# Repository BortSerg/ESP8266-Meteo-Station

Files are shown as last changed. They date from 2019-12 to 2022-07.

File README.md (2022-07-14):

# ESP8266-Meteo-Station
v14_07_2022.
1. Add auto load default settings in first start meteo station after firmware download.
2. Set DS18B20 outdoor sensor; BME280 room sensor.
3. Fix bug in 7-segment display light.
 
v11_02_2020.
1. Added the ability to update firmware via the web interface of the weather station. 
   You must go to the address http: // {IP Address} / update and specify *.bin firmware file.
2. Now there are 2 firmware in the project. With and without an RTC module. 
   In firmware without an RTC module, time is counted using the ESP8266 itself.

v07_02_2020.
Fix some bugs:
1. Fix display on the indicator of negative temperatures.
2. Fix changes the background color of the main web page at low temperatures.
3. Adding a button to adjust the brightness of the indicators on the main web page.
4. Decrease in manipulations at the first firmware of the device. Now you need to uncomment part of the code, flash, comment out and flash it again.

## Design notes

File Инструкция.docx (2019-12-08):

# Первый запуск

При первом включении метеостанции индикация на дисплее включается не сразу, некоторое время необходимо подождать, так как идет сканирование сетей, затем станция запускается в режиме точки доступа. На индикаторе в виде бегущей строки пробежит IP адрес 192.168.4.1. Для подключения к ней и дальнейшей конфигурации необходимо в списке доступный беспроводных сетей выбрать и подключиться к точке ESP8266.

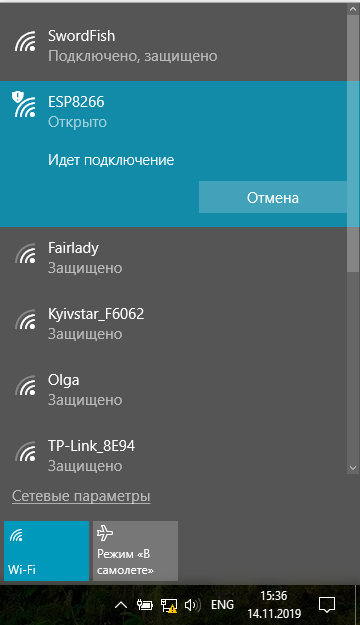
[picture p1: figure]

Далее в адресной строке браузера необходимо вписать данный IP адрес. Поле загрузки главной страницы с отображаемыми показаниями можно приступать к настройке метеостанции. В разделе Wi-Fi/AP задаются имя/пароль от вашей домашней беспроводной сети и имя/пароль точки доступа. Если у Вас соединения не защищенные паролем, то графы с паролями необходимо оставить пустыми. ВНИМАНИЕ! Во избежание некорректной работы метеостанции, графа с именем точки доступа должна быть ВСЕГДА заполнена. В случае неполадок в домашней беспроводной сети это позволит Вам подключиться к ней и изменить конфигурации. Графу с паролем можно не заполнять, если неуверены, что не забудете его в дальнейшем.

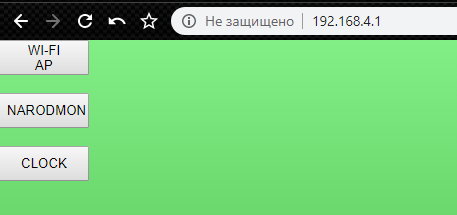
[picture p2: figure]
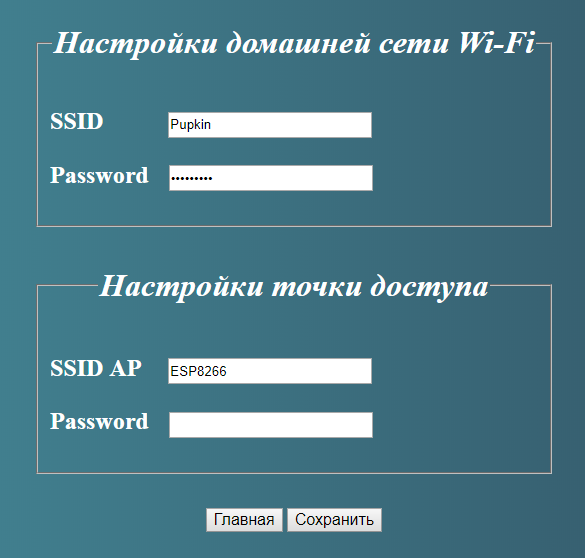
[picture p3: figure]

После конфигурирования сетевых параметров необходимо нажать кнопку «сохранить», а затем вручную перезагрузить устройство, отключив питание.

Без подключения к сети и доступа в интернет (работа в режиме точки доступа) невозможна отправка данных на Narodmon.ru и синхронизация часов с NTP серверами точного времени. Часы, в данном режиме работы, нужно будет корректировать вручную.

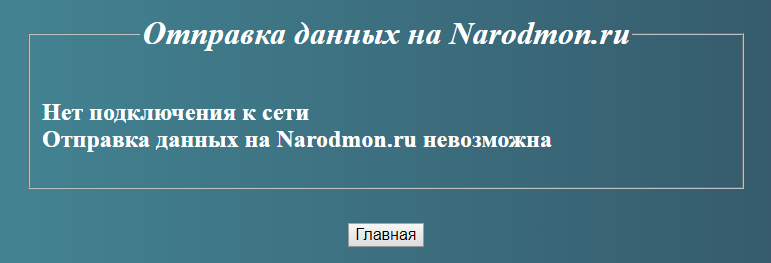
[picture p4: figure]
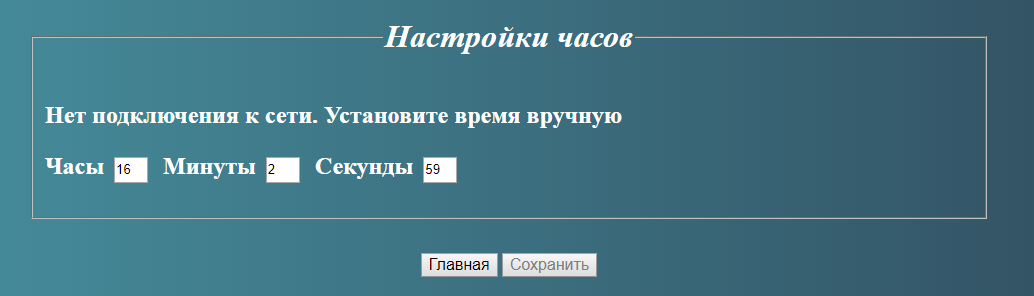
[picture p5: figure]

После перезагрузки, если Вы указали правильные параметры домашней сети, метеостанция подключится к вашему Wi-Fi роутеру и на индикаторе снова пробежит IP адрес, а точка доступа ESP8266 исчезнет. Подключившись к Вашему роутеру необходимо в адресной строке браузера ввести уже новый IP адрес.

Новый IP адрес можно будет использовать для доступа к метеостанции из вашей домашней сети. Теперь Вам будут доступны разделы с конфигурациями часов и Narodmon.ru.

# Narodmon.ru

Что такое Narodmon.ru? Это основанный в 2011 году краудфандинговый геоинформационный проект по отображению на карте мира и контролю (на ПК, смартфонах и других гаджетах) показаний датчиков своих участников (температуры, влажности, атм.давления, скорости и направления ветра, радиации, энергопотребления и любых других величин), а также частных и городских веб-камер для публичного или приватного просмотра.

Как это сделать? Сперва необходимо зарегистрироваться на сайте. Далее на метеостанции в соответствующих настройках разрешить ей отправку данных на сайт и указать таймаут отправки данных (меньше 5 минут нельзя, такова политика сайта). Затем на сайте в вкладке «профиль» выбрать пункт «Мои датчики».

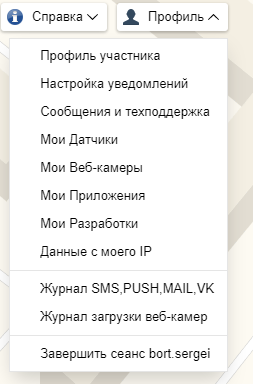
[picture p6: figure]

Далее кнопка «Добавить» и указать MAC метеостанции (для примера возьмем MAC CC:50:E3:2E:8A:79). Добавление возможно только после успешной передачи показаний метеостанции на сервер и верно указанного MAC.

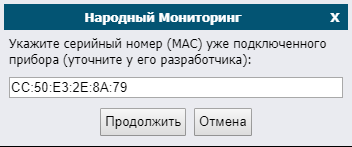
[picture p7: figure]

Если все указано верно и данные доставлены на сервера проекта, то в таблице ниже появятся данные которые приходят с метеостанции:

BME280P – атмосферное давление (мм.рт.ст.),

BME280Т – температура на улице (град. Цельсия),

BME280Н – влажность воздуха (%),

8e6f579970903c8 – датчик комнатной температуры (град. Цельсия).

Датчик комнатной температуры нельзя выводить в общий доступ.

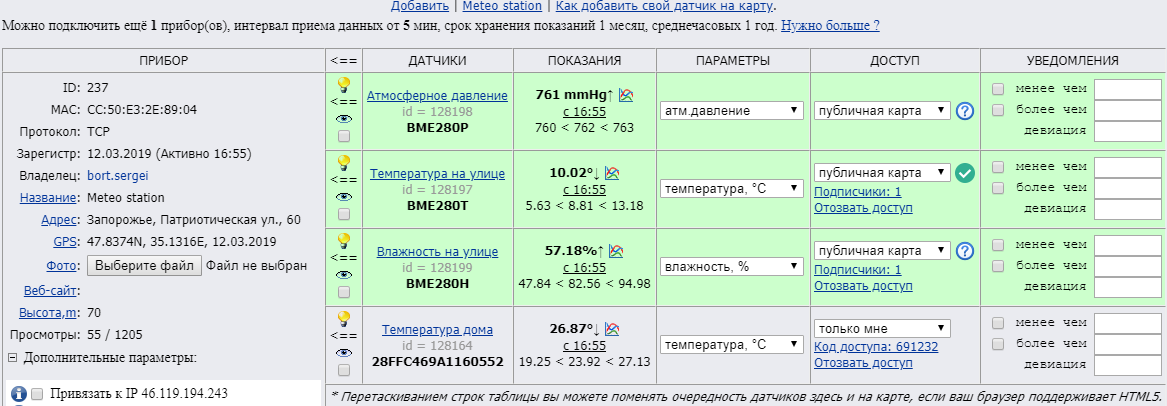
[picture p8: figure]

Выводя показания своих датчиков в публичный доступ, Вы обязуется разместить их "на улице" и принять меры по снижению влияния среды (прямых солнечных лучей, осадков, нагрева от стен строения) на достоверность показаний.

У проекта Narodmon есть мобильное приложение, которое позволит Вам с любой точки мира просматривать данные от ваших датчиков.

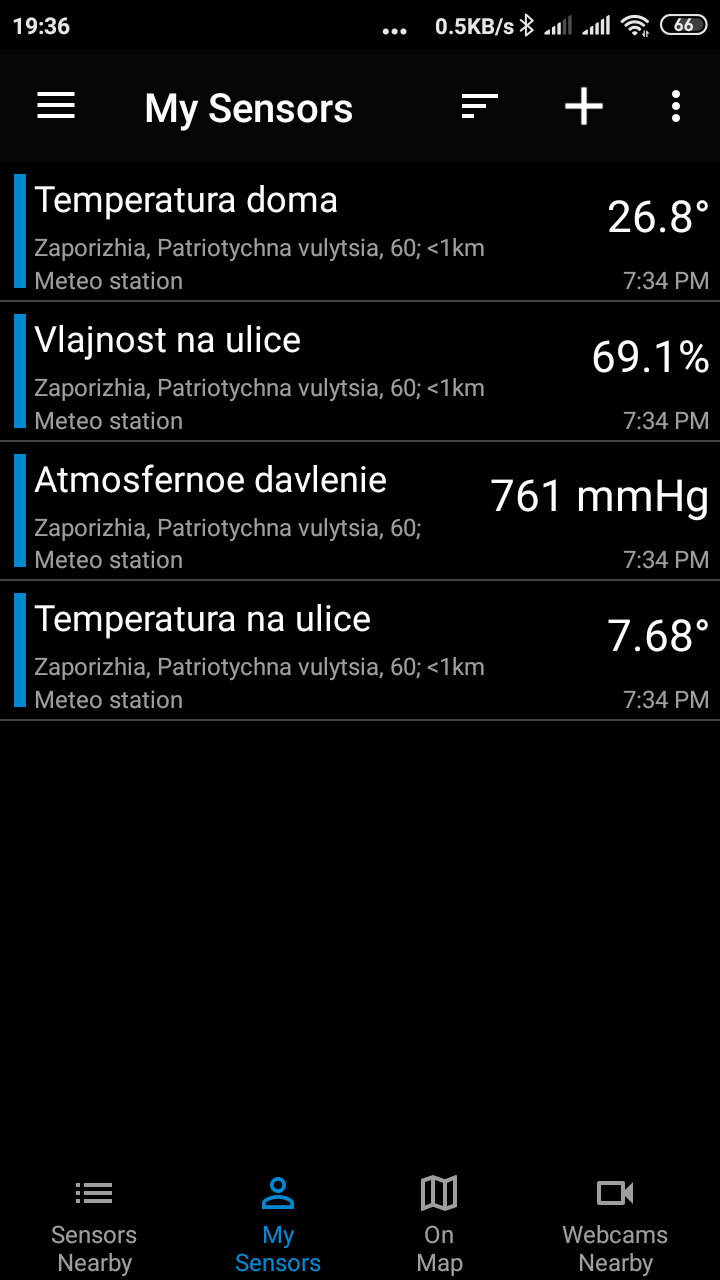
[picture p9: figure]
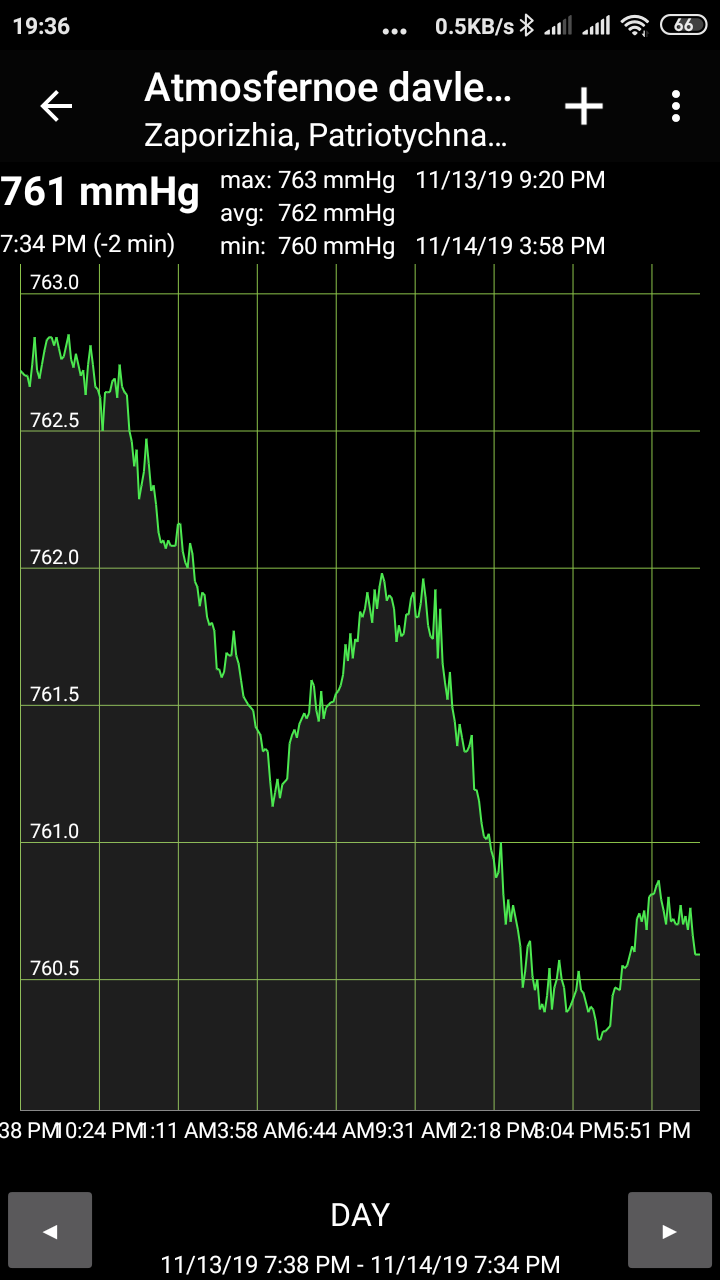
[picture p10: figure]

# Часы

Часы имеют функцию корректировки времени по NTP серверам точного времени. Для этого в конфигурации часов необходимо выбрать пункт «синхронизировать с NTP сервером», указать часовой пояс GMT (Greenwich Mean Time) в приделах от -11..0..12 и указать период с которым метеостанция будет сверять время с сервером. Интервал устанавливается в пределах от 1 часа до 168 часов (1 неделя).

Внутри метеостанции установлена микросхема часов реального времени (RTC DS1307Z) со своей памятью, что позволяет сохранять ход времени, даже если выключить метеостанцию. Точность хода составляет ±1-3 сек. в час. Если разница времени метеостанции и сервера NTP меньше 1 минуты, то синхронизация не производится.

Для перевода часов на летнее и зимнее время необходимо изменить часовой пояс GMT в большую или меньшую сторону на 1. Автоматический переход на летнее и зимнее время пока не предусмотрен в данной версии прошивки.

Если же в корректировке времени нет необходимости данную функцию можно отключить и выставить время вручную.

# Психотермометрическая будка

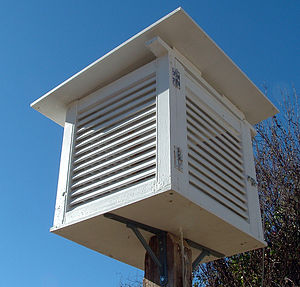
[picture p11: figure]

Датчик BME280 необходимо разместить на улице исключив попадание на него прямых солнечных лучей. В идеале такие датчики необходимо размещать в метеорологических будках, но поскольку на оконном отливе такое сооружение разместить проблематично, можно сделать импровизированную будку.

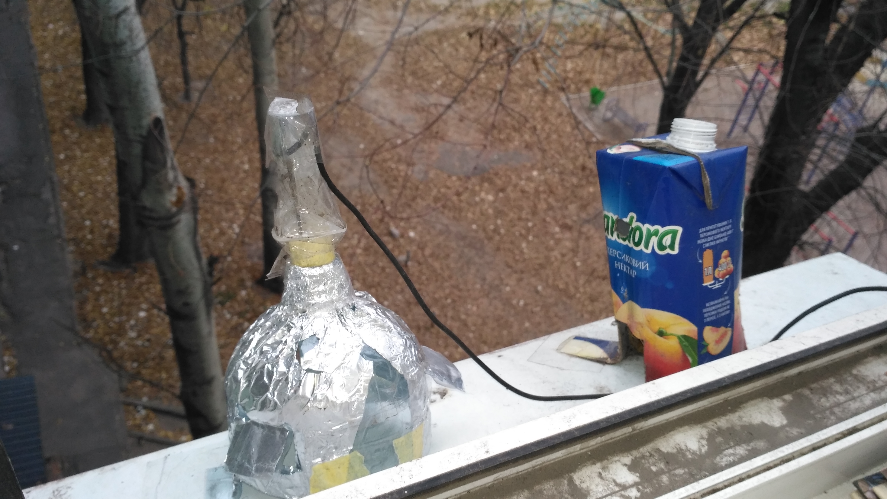
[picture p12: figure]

Корпус шприца идеально проходит в горлышко пластиковой бутылки от воды/напитка или в горлышко картонной упаковки сока. Если корпус из бутылки, то необходимо обернуть ее не проводящим свет материалом (фольга). Обязательно необходимо сделать отверстия для проветривания, это позволит не повышаться температуре внутри, при попадании прямых солнечных лучей, и не скапливаться конденсату, что может влиять на показания влажности.

Хоть наконечник штока шприца имеет резиновую прокладку, что обеспечивает хорошую гидроизоляцию, его можно обернуть скотчем, зафиксировав таким образом кабель и создав дополнительную гидроизоляцию. Кабель лучше всего направить вниз, так во время дождя по нему не будет стекать вода внутрь.

Пример импровизированной «будки»

# Дополнительные функции

1) Метеостанция имеет возможность изменять яркость свечения 7-сегментного индикатора. Для этого необходимо в адресной строке браузера ввести вручную [IP адрес]/settings_Light (http://192.168.1.4/settings_Light).

После этого будет доступно изменение яркости индикатора

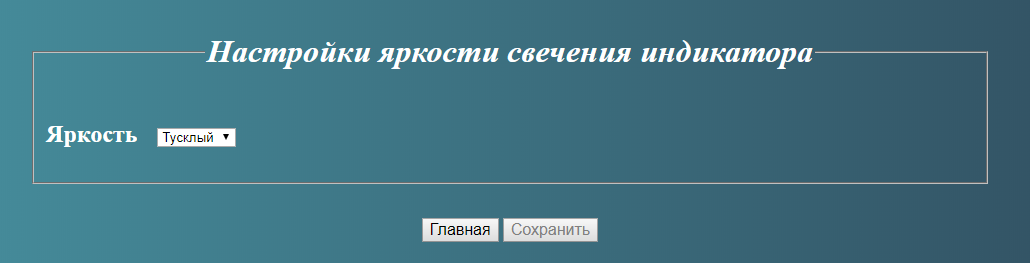
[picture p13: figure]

2) Имеется возможность перезагружать метеостанцию программно, но данная функция не всегда работает стабильно и иногда приводит к зависанию. Для перезагрузки необходимо в адресной строке браузера ввести [IP адрес]/reboot

После этого должна произойти перезагрузка и браузер автоматически перенаправит Вас на главную страницу.

Если же это привело к зависанию, то необходимо просто отключить питание метеостанции, а затем заново подключить.

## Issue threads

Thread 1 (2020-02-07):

ESP8266-Meteo-Station 07_02_2020

BortSerg, 2020-02-07:
1. Fix display on the indicator of negative temperatures
2. Fix for changing the background color of the main web page at low temperatures
3. Adding a button to adjust the brightness of the indicators on the main web page
4. Decrease in manipulations at the first firmware of the device. Now you need to uncomment part of the code, flash, comment out and flash it again.

Closed 2021-08-14.

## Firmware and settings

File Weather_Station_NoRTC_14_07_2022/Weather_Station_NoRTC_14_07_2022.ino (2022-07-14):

#include <ArduinoOTA.h>
#include <OneWire.h>
#include <ESP8266WiFi.h>
#include <WiFiClient.h>
#include <ESP8266WebServer.h>
#include <ESP8266HTTPUpdateServer.h>
#include <DallasTemperature.h>
#include "sntp.h"
#include <BME280I2C.h>
#include <Wire.h>
//#include <time.h>                            // закоментировать если не используется RTC
#include <TM1637.h>
#include <EEPROM.h>
//#include <WiFiClientSecure.h>              // для отправки в Telegram
#include <Ticker.h> //если не использовать модуль часов RTC раскоментировать

BME280I2C::Settings settings(
    BME280::OSR_X1,
    BME280::OSR_X1,
    BME280::OSR_X1,
    BME280::Mode_Forced,
    BME280::StandbyTime_1000ms,
    BME280::Filter_Off,
    BME280::SpiEnable_False,
    0x76 // I2C address. I2C specific.
);
BME280I2C bme(settings);

// I2C pins                                 //Wemos ESP8266
#define SDA_pin 4 // D2 pin
#define SCL_pin 5 // D1 pin

// инициализация oneWire и DS18B20
#define ONE_WIRE_BUS D4          // вывод к которому подключен DS18B20 он же GPIO1
#define TEMPERATURE_PRECISION 12 // точность бит. Если глючит или врет, уменьшить с 12 до 9

//  инициализация и установка адреся RTC
#define DS1307_I2C_ADDRESS 0x68

// определение пинов для вывода на индикаор ТМ1637
#define CLK D6
#define DIO D5

//Создаём объект класса TM1637, в качестве параметров передаём номера пинов подключения
TM1637 tm1637(CLK, DIO);
bool changeClock = false;
bool notChangeClock = false;

int NumberOfDevices; //сколько датчиков DS18B20 в системе.

// Переменные для часов
// uint32 Time;                              //время в UNIX формате
String timefull;        //время в формате dayweek month day 00:00:00 year
byte hours;             //часы
byte minutes;           //минуты
byte seconds;           //секунды
byte dayOfWeek;         //день недели
byte dayOfMonth;        //число месяца
byte month;             //месяц
byte year;              //год
byte sinc_count = 0;    //счечик попыток синхронизации часов
bool point_flag = true; //флаг для мигания разделителем при отображении часов
bool sync_clock = true; //флаг на разрешение синхронизации часов с сервером

// Переменные для таймингов
unsigned long previousMillis_TM1637 = 0;
unsigned long previousMillis_NM = 0;
unsigned long previousMillis_TL = 0;
unsigned long sync_previousMillis = 0;
unsigned long interval_TM1637 = 10000;  //интервал через который происходит смена значений на индикаторе
unsigned long interval_sync = 43200000; //интервал синхронизации часов
byte count = 0;                         //флаг смены значений на индикаторе
bool send_NM = true;                    //разрешение на отправку данных Narodmon.ru
unsigned long interval_NM = 300000;     //интервал отправки данных на Narodmon.ru
// bool          send_TL = true;               //разрешение на отправку данных Telegram
// unsigned long interval_TL = 300000;         //интервал отправки данных на Telegram

ESP8266HTTPUpdateServer httpUpdater;
ESP8266WebServer server(80);

WiFiClient client; // для отправки данных на narodmon.ru
// WiFiClientSecure httpsClient;               //для отправки даных в Telegram

OneWire oneWire(ONE_WIRE_BUS);
DallasTemperature DS18B20(&oneWire);

Ticker timer_clock; //объект класса, для вызова счетчика времени. Раскоментировать если нет RTC

// const uint16_t httpsPort = 443;             // порт Telegram bot
// const char* host = "api.telegram.org";      // хост Telegram bot
// SHA1 finger print of certificate use web browser to view and copy
// const char fingerprint[] PROGMEM = "bb dc 45 2a 07 e3 4a 71 33 40 32 da be 81 f7 72 6f 4a 2b 6b";
// String token = "";                          //api token
// String chat_id = "";                        //id чата с ботом
// String msg = "Start";                       //переменная для хранения сообщения которое будет отправленно в Telegram bot

struct ESP_Config
{                      //структура для хранения настроек метеостанции в EEPROM памяти. Переменные структуры записаны большими буквами, для их отличия от других глобальных переменных
  char MUSOR[16] = {}; //В начале сектора EEPROM содержатся какие-то данные ESP, запись туда важных данных нежелательна
  // Наименование в режиме клиента
  char WIFI_SSID[32] = {}; //имя сети
  char WIFI_PASSWORD[32] = {};
  // Параметры подключения в режиме точки доступа
  char AP_SSID[32] = {}; //имя точки доступа
  char AP_PASSWORD[32] = {};
  // Настройки часов
  int GMT = 0;               //часовой пояс
  bool SYNC_CLOCK = 0;       //разрешение на синхронизацию
  uint8_t INTERVAL_SYNC = 0; //интервал синхронизации часов
  // Настройки отправки данных на narodmon.ru
  bool SEND_NM = 0;        //разрешение на отправку данных Narodmon
  uint8_t INTERVAL_NM = 0; //интервал отправки данных
  // Настройки отправки сообщений в Telegram
  bool SEND_TL = 0;        //разрешение на отправку данных Telegram
  uint8_t INTERVAL_TL = 0; //интервал отправки данных
  char CHAT_ID[16] = {};   //Уникальный ID  чата
  char TOKEN[64] = {};     // API Token
  byte LIGHT = 0;          //Яркость 7-сегментного индикатора
  byte CONTROLL_VALUE = 0; //Контрольное значение = 88. Используется для определения загрузки дефолтных настроек при первом запуске
} Config;

void setup()
{

  Serial.begin(115200);
  Serial.println("");
  Serial.println("Soft ver. 14.07.2022");
  Serial.println("");
  EEPROM.begin(sizeof(Config)); //инициализация EEPROM памяти в размере = размеру структуры Config
  Serial.println("Инициализированно " + String(sizeof(Config)) + " byte EEPROM памяти");

  OTA_Update(); //подключение обновления по воздуху

  Read_Config(); // xтение конфига из EEPROM памяти конфигураций

  if (Config.CONTROLL_VALUE != 88) // проверка считаных с памяти данных. Если контрольное значение не верно, то записать дефолтные настройки
  {
    String ssid = "WiFiName";
    String pass = "";
    String ap_ssid = "ESP8266";
    String ap_pass = "";
    strcpy(Config.WIFI_SSID, ssid.c_str());
    strcpy(Config.WIFI_PASSWORD, pass.c_str());
    strcpy(Config.AP_SSID, ap_ssid.c_str());
    strcpy(Config.AP_PASSWORD, ap_pass.c_str());
    Config.SEND_NM = 5;
    Config.GMT = 0;
    Config.SYNC_CLOCK = 1;
    Config.INTERVAL_NM = 5;
    Config.INTERVAL_SYNC = 12;
    Config.LIGHT = 2;
    Config.CONTROLL_VALUE = 88;
    save_Config();
  }

  TM1637_init(); //Инициализация модуля TM1637

  SNTP_server_set(); //установка таймзоны и sntp серверов

  WiFi_init(); //подключение к сети и синхронизация часов/поднятие точки доступа

  Dalas18B20(); //поиск и инициализация датчиков DS18B20

  BME(); //поиск и инициализация датчика BME/BMP

  Init_html(); //инициализация HTML страниц сервера

  Serial.println("Temperature web server started!\n");

  timer_clock.attach(1, clock_); //прерывание для часов.  Раскоментировать если нет RTC

  IP_address_run(); //вывод IP адреса

  if (Config.SYNC_CLOCK == true & WiFi.status() == WL_CONNECTED)
    SyncRealTimeClock();
}

void loop()
{
  server.handleClient();
  ArduinoOTA.handle();
  delay(100);

  unsigned long currentMillis = millis();

  byte clock_view_count = 0;
  if ((currentMillis - previousMillis_TM1637 > interval_TM1637) & count == 0) //вывод часов
  {
    previousMillis_TM1637 = currentMillis;
    while (clock_view_count < 11)
    {
      viewTime();
      delay(1000);
      clock_view_count++;
    }
    clock_view_count = 0;
    count++;
  }

  if ((currentMillis - previousMillis_TM1637 > interval_TM1637) & count == 1) //вывод температуры в помещении
  {
    tm1637.point(false);
    previousMillis_TM1637 = currentMillis;
    getTM1637TemperatureRoom();
    count++;
  }

  if ((currentMillis - previousMillis_TM1637 > interval_TM1637) & count == 2) //вывод температуры на улице
  {
    previousMillis_TM1637 = currentMillis;
    getTM1637TemperatureOut();
    count++;
  }

  if ((currentMillis - previousMillis_TM1637 > interval_TM1637) & count == 3) //вывод атмосферного давления
  {
    previousMillis_TM1637 = currentMillis;
    getTM1637Pressure();
    count++;
  }

  if ((currentMillis - previousMillis_TM1637 > interval_TM1637) & count == 4) //вывод влажности воздуха
  {
    previousMillis_TM1637 = currentMillis;
    getTM1637Humidity();
    count = 0;
  }

  if ((currentMillis - sync_previousMillis > interval_sync)) //тайминг синхронизации часов с сервером
  {
    sync_previousMillis = currentMillis;
    if (Config.SYNC_CLOCK == true)
      SyncRealTimeClock();
  }

  if ((currentMillis - sync_previousMillis > interval_NM)) //тайминг синхронизации часов с сервером
  {
    sync_previousMillis = currentMillis;
    if (Config.SEND_NM == true)
      SendToNM();
  }
  /*
        if  ((currentMillis - previousMillis_TL > interval_TL))
              {
                previousMillis_TL = currentMillis;
                if (Config.SEND_TL == true) SendToTelegram();
              }

  */
  yield();
}

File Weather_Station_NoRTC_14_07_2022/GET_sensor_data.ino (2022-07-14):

//=================Получение тепературы с датчика DS18B20=================
float getTemperature() // 1-Wire ds18b20
{
  float temp;
  byte count = 0;
  do
  {
    DS18B20.requestTemperatures();
    temp = DS18B20.getTempCByIndex(0);
    delay(100);
    count++;
  } while ((temp <= (-50.0) || temp >= 85.0) & count <= 5);
  return temp;
}

//=================Получение тепературы c датчика BME280=================
float getTemperatureBME280()
{
  float temp;
  byte count = 0;
  do
  {
    temp = bme.temp();
    delay(100);
    count++;
  } while ((temp <= (-40.0) || temp >= 85.0) & count <= 5);
  return temp;
}

//=================Получение давления с датчика BME280===================
float getPressureBME280()
{
  float pres;
  byte count = 0;
  do
  {
    pres = bme.pres();
    delay(100);
    count++;
  } while ((pres <= 30000.0 || pres >= 110000.0) & count <= 5); //приделы в паскалях
  return pres;
}

//=================Получение влажности с датчика BME280==================
float getHumidityBME280()
{
  float hum;
  byte count = 0;
  do
  {
    hum = bme.hum();
    delay(100);
    count++;
  } while ((hum < 0.0 || hum > 100.0) & count <= 5);

  return hum;
}

//=================Функция вывода на ндикатор температуры в комнате=================
void getTM1637TemperatureRoom() //
{
  int temp = getTemperatureBME280(); //временная локальная переменная
  tm1637.display(0, 30);             //  t
  tm1637.display(1, 35);             //
  tm1637.display(2, 20);             //  i
  tm1637.display(3, 26);             //  n
  delay(600);
  tm1637.display(0, 30);        //  t
  tm1637.display(1, temp / 10); //  temp
  tm1637.display(2, temp % 10); //  temp
  tm1637.display(3, 36);        //  degree
}

//=================Функция вывода на ндикатор температуры на улице=================
void getTM1637TemperatureOut() //
{
  int temp = getTemperature(); //временная локальная переменная
  tm1637.display(0, 30);       //  t
  tm1637.display(1, 27);       //  o
  tm1637.display(2, 32);       //  u
  tm1637.display(3, 30);       //  t
  delay(600);

  if (temp <= -10)
  {
    tm1637.display(0, 34);             // -
    tm1637.display(1, abs(temp) / 10); // temp
    tm1637.display(2, abs(temp) % 10); // temp
    tm1637.display(3, 36);             // degree
  }

  if ((temp > -10) & (temp < 0))
  {
    tm1637.display(0, 30);             // t
    tm1637.display(1, 34);             // -
    tm1637.display(2, abs(temp) % 10); // temp
    tm1637.display(3, 36);             // degree
  }

  if ((temp >= 0) & (temp < 10))
  {
    tm1637.display(0, 30);        // t
    tm1637.display(1, 35);        // NULL
    tm1637.display(2, temp % 10); // temp
    tm1637.display(3, 36);        // degree
  }

  if (temp >= 10)
  {
    tm1637.display(0, 30);        //  t
    tm1637.display(1, temp / 10); //  temp
    tm1637.display(2, temp % 10); //  temp
    tm1637.display(3, 36);        //  degree
  }
}

//=================Функция вывода на ндикатор атмосферного давления=================
void getTM1637Pressure() //
{
  int temp = getPressureBME280() * 0.0075006157584566; //временная локальная переменная и перевод из паскалей в мм.рт.ст.

  tm1637.display(0, 28);                //  P
  tm1637.display(1, (temp / 100) % 10); //  presure
  tm1637.display(2, (temp / 10) % 10);  //  presure
  tm1637.display(3, (temp % 10));       //  presure
}

//=================Функция вывода на ндикатор влажности воздуха=====================
void getTM1637Humidity() //
{
  int temp = getHumidityBME280(); //временная локальная переменная

  if (temp <= 0)
  {
    tm1637.display(0, 17); //  H
    tm1637.display(1, 35); //  NULL
    tm1637.display(2, 0);  //  0
    tm1637.display(3, 37); //  _
  }
  if (temp >= 100)
  {
    tm1637.display(0, 17); //  H
    tm1637.display(1, 1);  //  1
    tm1637.display(2, 0);  //  0
    tm1637.display(3, 0);  //  0
  }
  else
  {
    tm1637.display(0, 17);        //  H
    tm1637.display(1, temp / 10); //  hum
    tm1637.display(2, temp % 10); //  hum
    tm1637.display(3, 37);        //  _
  }
}

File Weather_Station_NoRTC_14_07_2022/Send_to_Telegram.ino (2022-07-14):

/*void SendToTelegram()
{
   httpsClient.setFingerprint(fingerprint);
  httpsClient.setTimeout(15000);
  String TempIn = String(getTemperature());
  String TempOut = String(getTemperatureBME280());
  String Press = String(getPressureBME280()*0.0075006157584566);
  String Humi = String(getHumidityBME280());
      
 msg = "*Температура помещения:* " + TempIn + "*°C*%0A*Температура на улице:* " + TempOut + "*°C*%0A*Атмосферное давление:* " + Press + "*mmHg*%0A*Влажность воздуха:* " + Humi + "*%*";
 String Link = "/bot" + String(Config.TOKEN) +"/sendMessage?chat_id=" + String(Config.CHAT_ID) + "&parse_mode=Markdown&text=" + msg;
   Serial.print("HTTPS Connecting");
  int r=0; //retry counter
  while((!httpsClient.connect(host, httpsPort)) && (r < 30)){
      delay(100);
      Serial.print(".");
      r++;
  }
  if(r==30) {
    Serial.println("Connection failed");
  }
  else {
    Serial.println("Connected to web");
  
  Serial.print("requesting URL: ");
  Serial.println(host+Link);
 
  httpsClient.print(String("GET ") + Link + " HTTP/1.1\r\n" +
               "Host: " + host + "\r\n" +               
               "Connection: close\r\n\r\n");
 
  Serial.println("request sent");
                  
  while (httpsClient.connected()) {
    String line = httpsClient.readStringUntil('\n');
    if (line == "\r") {
      Serial.println("headers received");
      break;
    }
  }
 
  Serial.println("reply was:");
  Serial.println("==========");
  String line;
  while(httpsClient.available()){        
    line = httpsClient.readStringUntil('\n');  //Read Line by Line
    Serial.println(line); //Print response
  }
  Serial.println("==========");
  Serial.println("closing connection");
  }
}*/

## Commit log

2020-02-07 V07_02_2020
    Fix some bugs:
    1. Fix display on the indicator of negative temperatures
    2. Fix changes the background color of the main web page at low temperatures
    3. Adding a button to adjust the brightness of the indicators on the main web page
    4. Decrease in manipulations at the first firmware of the device. Now you need to uncomment part of the code, flash, comment out and flash it again.
    [AP_WIFI_init.ino, BME_searching.ino, DS18B20.ino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]
2022-07-14 v14_07_2022. 1. Add auto load default settings in first start meteo station after firmware download. 2. Set DS18B20 outdoor sensor; BME280 room sensor. 3. Fix bug in 7-segment display light.
    [AP_WIFI_init.ino, BME_searching.ino, DS18B20.ino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]
